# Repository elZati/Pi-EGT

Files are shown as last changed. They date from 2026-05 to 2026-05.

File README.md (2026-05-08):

# Pi-EGT

Marine boat instrument panel for Raspberry Pi 3 with a 5" DSI touchscreen (portrait mode, 480 × 800).

Displays exhaust gas temperature (EGT) in real time via a large circular analog gauge, logs a 15-minute rolling history, monitors ambient temperatures, and — when connected to WiFi — shows today's weather forecast and lightning storm risk.

---

## Hardware

| Component | Detail |
|---|---|
| Raspberry Pi 3 | Any variant |
| Raspberry Pi Touchscreen 2 (5") | DSI, 480 × 800 portrait |
| MAX31855 thermocouple amplifier | EGT sensor via SPI (CE0, 1 MHz) |
| DS18B20 temperature sensor(s) | Up to 2 on 1-Wire bus (GPIO 4) |
| Buzzer | EGT alarm via GPIO 17 (NPN transistor) |
| Custom HAT PCB | LM2596 buck converter from boat battery |

## Features

- **EGT gauge** — circular analog gauge with coloured zone arc (green / amber / red), digital readout and 15-minute scrolling histogram
- **Ambient temperature tiles** — shown automatically when DS18B20 sensors are detected; hidden if sensors disconnect (with 15-second timeout)
- **Buzzer alarm** — activates when EGT exceeds a configurable threshold
- **Weather panel** — today's forecast (icon, description, min/max °C) via [Open-Meteo](https://open-meteo.com/), selectable location
- **Lightning risk panel** — Low / Moderate / High / Active derived from CAPE and WMO weather codes
- **Adaptive poll rate** — 4 Hz normally, drops to 1 Hz if the Pi CPU exceeds 70 °C
- **Portrait layout** — all panels stack vertically; weather and lightning panels are hidden by default and revealed on demand (histogram hides to make room)
- **Setup dialog** — configure EGT gauge min/max, alarm threshold, and mock sensor mode without restarting
- **Fullscreen toggle** — hides the OS taskbar for a clean instrument view
- **Auto-start on boot** via XDG autostart (`~/.config/autostart/pi-egt.desktop`)

## Requirements

```
PyQt5 >= 5.15
requests >= 2.28
spidev >= 3.5      # Pi only
RPi.GPIO >= 0.7    # Pi only
```

Install on the Pi:

```bash
pip3 install -r requirements.txt
```

## Pi OS configuration

Add to `/boot/firmware/config.txt` and reboot:

```ini
dtparam=spi=on        # MAX31855
dtoverlay=w1-gpio     # DS18B20
```

## Running

```bash
cd ~/pi-egt
DISPLAY=:0 python3 main.py            # normal mode
DISPLAY=:0 python3 main.py --mock     # simulated sawtooth sensors
```

Mock mode can also be toggled at runtime from the **Setup** dialog.

## Deployment to Pi

```bash
# Copy project
scp -r . pi@<pi-ip>:~/pi-egt/

# Install desktop shortcut
ssh pi@<pi-ip> "cp ~/pi-egt/pi-egt.desktop ~/Desktop/ && chmod +x ~/Desktop/pi-egt.desktop"

# Install autostart (runs on every boot)
ssh pi@<pi-ip> "mkdir -p ~/.config/autostart && cp ~/pi-egt/pi-egt.desktop ~/.config/autostart/"
```

## Project structure

```
Pi-EGT/
├── main.py                   Entry point; --mock flag; dark Qt palette
├── pi-egt.desktop            Desktop / autostart launcher
├── requirements.txt
├── docs/
│   ├── notes.md              Hardware design notes, PCB, BOM
│   └── software.md           Full software description & architecture
└── pi_egt/
    ├── config.py             Constants and user config (load/save JSON)
    ├── sensors/
    │   ├── max31855.py       SPI thermocouple reader
    │   ├── ds18b20.py        1-Wire temperature reader
    │   └── buzzer.py         GPIO buzzer
    ├── network/
    │   ├── connectivity.py   TCP reachability check
    │   ├── weather.py        Open-Meteo API client
    │   ├── lightning.py      Lightning risk assessment
    │   └── fetch_thread.py   Non-blocking QThread fetch
    └── ui/
        ├── main_window.py    Main window, layout, timers
        └── widgets/
            ├── egt_gauge.py
            ├── histogram.py
            ├── temp_tile.py
            ├── weather_panel.py
            ├── lightning_panel.py
            ├── setup_dialog.py
            └── location_dialog.py
```

## License

MIT

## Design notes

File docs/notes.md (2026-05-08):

# Pi-EGT Boat Instrument — Hardware Notes

## Overview

Raspberry Pi 3 based boat instrument panel displaying EGT (exhaust gas temperature),
coolant temperature, and ambient temperatures. Includes alarm buzzer for EGT threshold.

---

## Power Supply

### LM2596 Buck Converter
- Input: 10–15V boat battery
- Output: 5V / 3A
- IC: LM2596S-5.0 (TO-263 SMD, fixed 5V)
- Switching frequency: 150kHz
- Input protection diode: SS34 on battery+ input (reverse polarity protection)

### LC Post Filter
- Inductor: 4.7µH (Wurth 7440530047)
- Capacitor: 100µF 10V tantalum D case
- Purpose: reduces LM2596 switching ripple before Pi supply

### Pi Power Connection
- Feed 5V to Pi GPIO header **pin 2** or **pin 4**
- GND to any Pi GND pin
- 100nF decoupling cap + 10µF bulk cap at Pi header pins
- Do NOT use micro USB for power in this installation

---

## GPIO Pin Assignments

| GPIO (BCM) | Physical pin | Function |
|---|---|---|
| GPIO4 | pin 7 | 1-Wire bus — DS18B20 temperature sensors |
| GPIO7 | pin 26 | SPI CE1 — MAX31855 #2 chip select |
| GPIO8 | pin 24 | SPI CE0 — MAX31855 #1 chip select |
| GPIO9 | pin 21 | SPI MISO — shared by both MAX31855 |
| GPIO11 | pin 23 | SPI SCLK — shared by both MAX31855 |
| GPIO17 | pin 11 | Buzzer driver output |

---

## Sensors

### DS18B20 — 1-Wire Temperature Sensors
- Two sensors on a single 1-Wire bus
- Protocol: Dallas 1-Wire
- Power: 3.3V from Pi header pin 1 (3-wire mode recommended for marine)
- Data pin: GPIO4 (Pi physical pin 7)
- Pull-up: single 4.7kΩ resistor from DQ to 3.3V (shared by all sensors)
- Connected via 3-position Phoenix Contact screw terminal (VDD / GND / DQ)

**Enable 1-Wire on Pi — add to `/boot/config.txt`:**
```
dtoverlay=w1-gpio
```

**Read temperature:**
```python
# Sensors appear as folders under /sys/bus/w1/devices/
# Named like: 28-xxxxxxxxxxxx
# Temperature in millidegrees C

import glob

sensor_paths = glob.glob('/sys/bus/w1/devices/28-*/temperature')

for path in sensor_paths:
    with open(path) as f:
        temp_mc = int(f.read())
        temp_c = temp_mc / 1000.0
        print(f'{path}: {temp_c:.1f}°C')
```

---

### MAX31855 — Thermocouple Amplifier (EGT + Coolant)
- Two MAX31855 boards (Adafruit breakout)
- Protocol: SPI (read-only, MISO only — no MOSI needed)
- Power: 3.3V
- MAX31855 #1 (EGT): CS on GPIO8 (CE0)
- MAX31855 #2 (Coolant/second EGT): CS on GPIO7 (CE1)
- SCLK: GPIO11 (shared)
- MISO: GPIO9 (shared)
- SPI clock speed: 1MHz recommended (tolerant of long cable run)

**Remote sensor connection:**
- Sensor located at aft of boat
- Connected to Pi hat via Molex 8-pin connector
- Series resistors on Pi hat side: 33Ω on CLK, CS1, CS2, MISO (GPIO protection)
- Common mode chokes on sensor side (already on Adafruit board)
- Cable: twist signal pairs with GND for noise rejection

**Molex 8-pin connector pinout:**

| Pin | Signal | Notes |
|-----|---|---|
| 8 | spare | — |
| 7 | 3.3V | Power |
| 6 | 3.3V | Second power pin |
| 5 | TH_3V0 | MAX31855 3V output — leave unconnected on Pi side |
| 4 | GND | Ground |
| 3 | TH_DO / MISO | Data from sensor |
| 2 | TH_CS / CE0 | Chip select — MAX31855 #1 |
| 1 | TH_CLK | SPI clock |

**Read thermocouple with Python:**
```python
import spidev

spi = spidev.SpiDev()
spi.open(0, 0)          # bus 0, CE0 — MAX31855 #1
spi.max_speed_hz = 1000000
spi.mode = 1

def read_max31855(cs):
    spi.open(0, cs)
    raw = spi.readbytes(4)
    spi.close()
    value = (raw[0] << 24) | (raw[1] << 16) | (raw[2] << 8) | raw[3]
    if value & 0x7:
        return None     # fault detected
    temp_raw = (value >> 18) & 0x3FFF
    if temp_raw & 0x2000:
        temp_raw -= 0x4000
    return temp_raw * 0.25

egt_temp   = read_max31855(0)   # CE0 — EGT sensor
cool_temp  = read_max31855(1)   # CE1 — coolant sensor
```

---

## Buzzer Alarm

- Buzzer: Same Sky CMI-1295-0585T (5V active, internally driven, through-hole, 5mm pin pitch)
- Driver: BC817-25 NPN transistor (SOT-23)
- GPIO: GPIO17 (Pi physical pin 11)
- Circuit: GPIO17 → 1kΩ R_BASE → transistor base, 10kΩ R_PULL to GND, SS14 flyback diode across buzzer
- Power: 5V rail

**Buzzer control:**
```python
import RPi.GPIO as GPIO

BUZZER_PIN = 17

GPIO.setmode(GPIO.BCM)
GPIO.setup(BUZZER_PIN, GPIO.OUT)

def buzzer_on():
    GPIO.output(BUZZER_PIN, GPIO.HIGH)

def buzzer_off():
    GPIO.output(BUZZER_PIN, GPIO.LOW)
```

**EGT alarm example:**
```python
EGT_ALARM_THRESHOLD = 800   # degrees C — adjust to suit engine

def check_egt_alarm(egt_temp):
    if egt_temp is not None and egt_temp > EGT_ALARM_THRESHOLD:
        buzzer_on()
    else:
        buzzer_off()
```

---

## Display

- 5 inch DSI touchscreen connected to Pi DSI port
- Draws 5V from Pi's 5V rail
- DSI interface logic handled internally by Pi
- No extra power wiring needed for display

---

## BOM Summary (DigiKey part numbers)

| Ref | Part number | Qty | Description |
|-----|---|-----|---|
| U1 | LM2596S-5.0/NOPB | 1 | DC-DC regulator IC |
| L1 | SRR1260-330M | 1 | 33µH main inductor |
| L2 | 7440530047 | 1 | 4.7µH post filter inductor |
| D1, D2 | SS34-HF | 2 | Schottky diode 3A/40V |
| D3 | SS14-E3/61T | 1 | Flyback diode buzzer |
| Q1 | BC817-25LT1G | 1 | NPN transistor buzzer driver |
| F1 | 3568-15 | 1 | ATO fuse holder 5A |
| BZ1 | CMI-1295-0585T | 1 | 5V active buzzer |
| C_OUT, C_POST | T491D107K010AT | 2 | 100µF 10V tantalum D case |
| C1-C3, C6 | CC0805KRX7R9BB104 | 4 | 100nF X7R 0805 |
| R4 | RC0805FR-074K7L | 1 | 4.7kΩ 1-Wire pull-up |
| R5,R6,R7,R10 | RC0805FR-0733RL | 4 | 33Ω SPI series resistors |
| R_BASE, R_ONOFF | RC0805FR-071KL | 2 | 1kΩ 0805 |
| R_PULL, R8 | RC0805FR-0710KL | 2 | 10kΩ 0805 |
| J_TEMP | 1751251 | 1 | Phoenix 3-pos 3.5mm terminal |
| J_PWR | 1715022 | 1 | Phoenix 2-pos 5mm terminal |

---

## PCB Design Rules (PCBWay standard 2-layer)

| Parameter | Value |
|---|---|
| Min clearance | 0.127mm |
| Min track width | 0.127mm |
| Min via diameter | 0.6mm |
| Min via drill | 0.3mm |
| Min hole to hole | 0.5mm |
| Hole clearance | 0.25mm |
| Copper to edge | 0.3mm |
| Min text height | 1.0mm |
| Min text stroke | 0.15mm |

### Recommended track widths

| Net | Width |
|-----|---|
| 5V power | 2.0mm |
| 3.3V power | 1.0mm |
| Signal (SPI, 1-Wire) | 0.25mm |
| LM2596 switch node | 2.5mm (short as possible) |

### Recommended via sizes

| Type | Outer dia | Drill |
|---|---|---|
| Signal | 0.8mm | 0.4mm |
| Power / GND stitch | 1.0mm | 0.5mm |
| LM2596 thermal (×6) | 1.0mm | 0.5mm |

---

## Useful Libraries for Pi Development

```bash
pip install RPi.GPIO spidev w1thermsensor adafruit-circuitpython-max31855
```

- `RPi.GPIO` — GPIO control (buzzer)
- `spidev` — raw SPI access (MAX31855)
- `w1thermsensor` — DS18B20 1-Wire (simpler than reading sysfs directly)
- `adafruit-circuitpython-max31855` — Adafruit MAX31855 library

---

## Notes

- Conformal coat all PCBs after assembly — marine salt air environment
- Enable Pi hardware watchdog in software for unattended operation
- Keep SPI clock at 1MHz for long cable run to aft sensor
- LM2596 switch node (pin 2 / inductor / catch diode) — keep traces short and wide
- Keep feedback trace (LM2596 pin 4) away from inductor
- LM2596 TO-263 tab needs copper pour + 6 thermal vias for heat dissipation
- Ground plane on B.Cu flood filled with GND net
- Stitch F.Cu and B.Cu ground planes with vias throughout board

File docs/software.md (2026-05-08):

# Pi-EGT Software — Description & Architecture

## What it is

Pi-EGT is a marine instrument panel application for Raspberry Pi 3 with a 5-inch DSI
touchscreen.  It displays exhaust gas temperature (EGT) and ambient temperatures in
real time, triggers a buzzer alarm when EGT exceeds a configurable threshold, and
optionally shows today's weather forecast and lightning storm risk when the Pi has a
network connection.

---

## Running the app

```bash
cd ~/pi-egt
DISPLAY=:0 python3 main.py          # real hardware
DISPLAY=:0 python3 main.py --mock   # simulated sensors (development)
```

`--mock` forces all sensors into simulation mode regardless of whether the hardware
interfaces are present.  Useful when the sensors are not yet connected.

Mock mode can also be toggled at runtime from the Setup dialog without restarting.

User settings (EGT range, alarm threshold, mock mode, saved location) are stored in
`~/.pi_egt/config.json` and loaded automatically on startup.

---

## Screen layout  (480 × 800 portrait, Raspberry Pi Touchscreen 2)

```
┌────────────── 480 ───────────────┐
│                                  │
│          EGT analog gauge        │  stretch 8
│       (large circular, full      │
│        width, dominant)          │
│                                  │
├──────────────────────────────────┤
│       15-minute EGT histogram    │  stretch 2
├──────────────────────────────────┤
│   Ambient 1    │    Ambient 2    │  stretch 2 (hidden if no sensors)
├──────────────────────────────────┤
│       Lightning risk panel       │  stretch 2 (hidden by default)
├──────────────────────────────────┤
│       Weather panel              │  stretch 2 (hidden by default)
├──────────────────────────────────┤
│ [⚙ Setup][⚡ Ltng][▼ Wth][⛶ Full]│  fixed 44 px
└──────────────────────────────────┘
```

All sections stack top-to-bottom (portrait orientation).

**Dynamic visibility rules:**
- Ambient temperature row appears only when DS18B20 sensors are detected (or mock
  mode is active).  Hidden entirely when no 1-Wire sensors are found.
- Lightning panel is hidden on startup.  Tap **⚡ Lightning** to reveal it.
- Weather panel is hidden on startup.  Tap **▼ Weather** to reveal it.

---

## Sensors

### MAX31855 — EGT thermocouple (SPI)

| Item | Detail |
|---|---|
| Interface | SPI bus 0, CE0 (`/dev/spidev0.0`) |
| Clock speed | 1 MHz (tolerant of long cable run to aft sensor) |
| Poll rate | 1 second |
| Mock | Sawtooth 0 → 1000 °C, period ~120 s |

`None` is returned on any fault condition (open circuit, short to VCC/GND).  The
gauge shows **FAULT** and the buzzer stays silent.

### DS18B20 — Ambient temperature (1-Wire)

| Item | Detail |
|---|---|
| Interface | 1-Wire on GPIO 4 (`/sys/bus/w1/devices/28-*`) |
| Sensors | Up to 2 on one bus |
| Poll rate | 1 second (same timer as EGT) |
| Mock | Sawtooth 0 → 100 °C, period ~60 s; sensor 2 offset by 50 °C |

If the 1-Wire bus is present but no `28-*` sensor files are found, the driver
automatically falls back to mock data rather than showing blank tiles.

The `sensor_count` property exposes how many sensors are active (2 in mock mode,
actual discovered count in hardware mode).  `MainWindow` uses this to show or hide
the ambient temperature tiles dynamically.

### Buzzer — EGT alarm (GPIO 17)

Driven via NPN transistor (BC817-25).  The buzzer activates whenever the EGT reading
exceeds the configured alarm threshold.  It deactivates as soon as the reading drops
back below the threshold.  On Pi OS the driver uses `RPi.GPIO`; off-Pi it is a no-op.

---

## EGT gauge

A custom `QPainter`-drawn circular gauge rendered in a virtual 300 × 300 coordinate
space and scaled to fill the available widget area.

**Configurable range** — the gauge min, max, and alarm threshold are all user-settable
via the Setup dialog.  Changes take effect immediately without restarting.

**Zone colours** — derived at runtime from the alarm threshold:

| Zone | Range | Colour |
|---|---|---|
| Safe | min → alarm × 0.85 | Green `#27ae60` |
| Caution | alarm × 0.85 → alarm | Amber `#f39c12` |
| Danger | alarm → max | Red `#e74c3c` |

When the alarm threshold changes the colour arc boundaries redraw automatically.

**Tick labels** — font 11 px bold, placed at radius 76 (well inside the colour arc at
radius 110) so they never overlap the arc.  Step size is computed from the display
range (100 °C steps for 0–1000 °C, 50 °C for smaller ranges, etc.).

---

## 15-minute EGT histogram

Keeps a rolling `deque` of `(monotonic_timestamp, temperature)` pairs covering the
last 15 minutes (900 seconds).  Readings older than 15 minutes are pruned on every
new reading.

The histogram spans the full window width below the top row.

The Y-axis scale matches the gauge max setting and redraws correctly when the range
is changed via Setup.  Grid-line and label steps are computed dynamically:

| Max temp | Step |
|---|---|
| ≤ 200 °C | 50 °C |
| ≤ 500 °C | 100 °C |
| > 500 °C | 200 °C |

---

## Setup dialog

Opened via the **⚙ Setup** button (bottom-left, 44 px tall touch target).

| Setting | Default | Step | Range |
|---|---|---|---|
| Gauge Min | 0 °C | 50 °C | 0 – 500 °C |
| Gauge Max | 1000 °C | 50 °C | 200 – 1200 °C |
| Alarm Threshold | 800 °C | 10 °C | 100 – 1200 °C |
| Mock Sensors | OFF | toggle | — |

On **Save**:
- Alarm is automatically clamped to the display range.
- Gauge Min is clamped so that Max − Min ≥ 100 °C.
- Values are applied immediately to the gauge, histogram, and alarm logic.
- If mock mode changed, sensors are re-initialised in place and tile visibility
  is updated without restarting the app.
- Settings are persisted to `~/.pi_egt/config.json`.

---

## Weather panel

Requires an internet connection (checked before every fetch via a TCP probe to
`8.8.8.8:53`).  When offline, all panels show "No network" and retry on the next
scheduled tick.

**Hidden by default** — tap **▼ Show weather** to reveal it.  The button turns green
when weather is hidden as a reminder that it is available.

**Data source:** [Open-Meteo](https://open-meteo.com/) — free, no API key required.

**What is shown:**
- Location name (city)
- Today's dominant weather icon and description (WMO weather code)
- Today's min / max temperature (°C)

**Location selection:** tap the **⚙** button inside the weather panel to open a city
search dialog.  The geocoding API is also Open-Meteo.  Selected location is saved to
`~/.pi_egt/config.json`.

**Sensor poll rate:** adaptive — 250 ms (4 Hz) normally; drops to 1000 ms when the
Pi CPU temperature exceeds 70 °C, and restores once it falls back below 65 °C.
The CPU temperature is sampled every 10 seconds from
`/sys/class/thermal/thermal_zone0/temp`.  On non-Pi hardware the fast rate is
always used.

**Fetch interval:** every 15 minutes.  Each fetch runs in a one-shot `QThread`
(`FetchThread`) so the UI is never blocked.  After the thread finishes it is deleted
and the reference cleared; only one fetch runs at a time.

**Connectivity retry:** the first fetch fires 10 seconds after startup (to give WiFi
time to connect on autostart).  If the network is unreachable, the app retries every
30 seconds for up to 10 minutes (20 attempts).  The retry stops automatically on the
first successful fetch; the regular 15-minute timer continues independently.

---

## Lightning risk panel

Derived from the same Open-Meteo fetch as the weather data (no separate API call).
Full width, hidden by default — tap **⚡ Lightning** to show it.

| Level | Trigger |
|---|---|
| Low | Default — no elevated CAPE or thunderstorm code |
| Moderate | CAPE ≥ 500 J/kg  or  lightning potential ≥ 40 % |
| High | CAPE ≥ 1000 J/kg  or  lightning potential ≥ 70 % |
| Active | Current-hour WMO weather code is 95, 96, or 99 (thunderstorm) |

When **Active**, the panel background turns dark red as a visual alarm.

---

## Panel toggles

Four buttons in the 44 px bar at the bottom control what is visible:

| Button | Hidden state | Shown state |
|---|---|---|
| ⚡ Lightning | Yellow tint | Normal, "Hide lightning" |
| ▼ Weather | Green tint | Normal, "▲ Hide weather" |

When a panel is hidden its stretch is removed from the layout, giving more vertical
space to the gauge and histogram.  Both panels are hidden on startup.

---

## Fullscreen toggle

The **⛶ Fullscreen** button (44 px, bottom-right) switches between windowed and
fullscreen mode.  In fullscreen mode the OS taskbar and window decorations are
hidden, giving the instrument the full 800 × 480 display.  Pressing **⊞ Windowed**
restores the normal windowed view.

---

## Desktop shortcut

`pi-egt.desktop` in the project root is a standard `.desktop` launcher for the Pi OS
desktop environment.  To install it on the Pi:

```bash
cp ~/pi-egt/pi-egt.desktop ~/Desktop/
chmod +x ~/Desktop/pi-egt.desktop
```

The shortcut launches the app from the desktop without opening a terminal.

---

## Auto-start on boot

`~/.config/autostart/pi-egt.desktop` is installed on the Pi.  The XDG autostart
mechanism starts the app automatically whenever the desktop session loads (Pi OS
auto-logs in as `pi` by default, so this fires on every boot).

A `sleep 8` delay is built into the launch command to give the display server time
to finish initialising before the app starts.

To disable auto-start:
```bash
rm ~/.config/autostart/pi-egt.desktop
```

---

## Project structure

```
Pi-EGT/
├── main.py                        Entry point; --mock flag; dark Qt palette
├── pi-egt.desktop                 Desktop shortcut (copy to ~/Desktop/ on Pi)
├── requirements.txt
├── docs/
│   ├── notes.md                   Hardware design notes, PCB, BOM
│   └── software.md                This file
└── pi_egt/
    ├── config.py                  All constants + user config load/save
    ├── sensors/
    │   ├── max31855.py            SPI reader / sawtooth mock
    │   ├── ds18b20.py             1-Wire reader / sawtooth mock; sensor_count property
    │   └── buzzer.py              GPIO buzzer / no-op mock
    ├── network/
    │   ├── connectivity.py        TCP reachability check
    │   ├── weather.py             Open-Meteo API client (weather + geocoding)
    │   ├── lightning.py           Lightning risk assessment from weather data
    │   └── fetch_thread.py        One-shot QThread for non-blocking fetch
    └── ui/
        ├── main_window.py         QMainWindow — vertical layout, timers, signal wiring
        └── widgets/
            ├── egt_gauge.py       Circular analog gauge (QPainter)
            ├── histogram.py       15-minute scrolling EGT chart (QPainter)
            ├── temp_tile.py       Digital ambient temperature tile
            ├── weather_panel.py   Compact today-only weather display
            ├── lightning_panel.py Lightning risk level display
            ├── setup_dialog.py    EGT range + alarm + mock mode configuration
            └── location_dialog.py City search + selection dialog
```

---

## Pi configuration requirements

The following must be enabled in `/boot/firmware/config.txt` before the hardware
sensors will work:

```ini
dtparam=spi=on        # MAX31855 thermocouple
dtoverlay=w1-gpio     # DS18B20 1-Wire sensors
```

A reboot is required after enabling these overlays.

---

## Dependencies

| Package | Purpose | Pi only? |
|---|---|---|
| `PyQt5 ≥ 5.15` | UI framework | No |
| `requests ≥ 2.28` | Weather API HTTP | No |
| `spidev ≥ 3.5` | MAX31855 SPI | Yes |
| `RPi.GPIO ≥ 0.7` | Buzzer GPIO | Yes |

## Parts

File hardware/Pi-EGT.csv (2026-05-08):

Reference | Value | Datasheet | Footprint | Qty | DNP
BZ1 | Buzzer |  | Buzzer_Beeper:Buzzer_TDK_PS1240P02BT_D12.2mm_H6.5mm | 1
C1,C2,C3,C6 | 100n | https://cdn.sparkfun.com/assets/8/a/4/a/5/Kemet_Capacitor_Datasheet.pdf | Capacitor_SMD:C_0805_2012Metric_Pad1.18x1.45mm_HandSolder | 4
C4,C7 | 100u |  | Capacitor_Tantalum_SMD:CP_EIA-7343-20_Kemet-V_HandSolder | 2
C5 | 220u |  | Capacitor_Tantalum_SMD:CP_EIA-7343-20_Kemet-V_HandSolder | 1
D1,D2 | SS34 | https://www.vishay.com/docs/88751/ss32.pdf | Diode_SMD:D_SMA | 2
D4 | SS14 | https://www.vishay.com/docs/89018/mss1p6.pdf | PCM_SparkFun-Semiconductor-Standard:SMA | 1
F1 | Fuse |  | Fuse:Fuseholder_Blade_Mini_Keystone_3568 | 1
J1 | GPIO |  | Connector_PinSocket_2.54mm:PinSocket_2x20_P2.54mm_Vertical | 1
J2,J6 | 446200001 |  | EGT-Connector:CON_SD44620_15P75X15P11_MOL | 2
J4 | 3.5mm | https://cdn.sparkfun.com/assets/b/1/8/d/9/OSTTEXX0104.pdf | TerminalBlock_Phoenix:TerminalBlock_Phoenix_PT-1,5-3-3.5-H_1x03_P3.50mm_Horizontal | 1
J5 | Screw_Terminal_01x02 |  | TerminalBlock_Phoenix:TerminalBlock_Phoenix_MKDS-3-2-5.08_1x02_P5.08mm_Horizontal | 1
L1 | L_Ferrite_Small |  | Inductor_SMD:L_Bourns_SRR1260 | 1
L2 | 4.7 uH | https://www.we-online.com/catalog/datasheet/7440530047.pdf?ki | Wurth_coils:L_Wurth_WE-TPC-5828 | 1
Q1 | BC817 | https://www.onsemi.com/pub/Collateral/BC818-D.pdf | Package_TO_SOT_SMD:SOT-23 | 1
R4 | 4k7 |  | Resistor_SMD:R_0805_2012Metric_Pad1.20x1.40mm_HandSolder | 1
R5,R6,R7,R10 | 33 |  | Resistor_SMD:R_0805_2012Metric_Pad1.20x1.40mm_HandSolder | 4
R8 | 10k |  | Resistor_SMD:R_0805_2012Metric_Pad1.20x1.40mm_HandSolder | 1
R9 | 1k |  | Resistor_SMD:R_0805_2012Metric_Pad1.20x1.40mm_HandSolder | 1
U2 | LM2596S-5 | http://www.ti.com/lit/ds/symlink/lm2596.pdf | Package_TO_SOT_SMD:TO-263-5_TabPin3 | 1

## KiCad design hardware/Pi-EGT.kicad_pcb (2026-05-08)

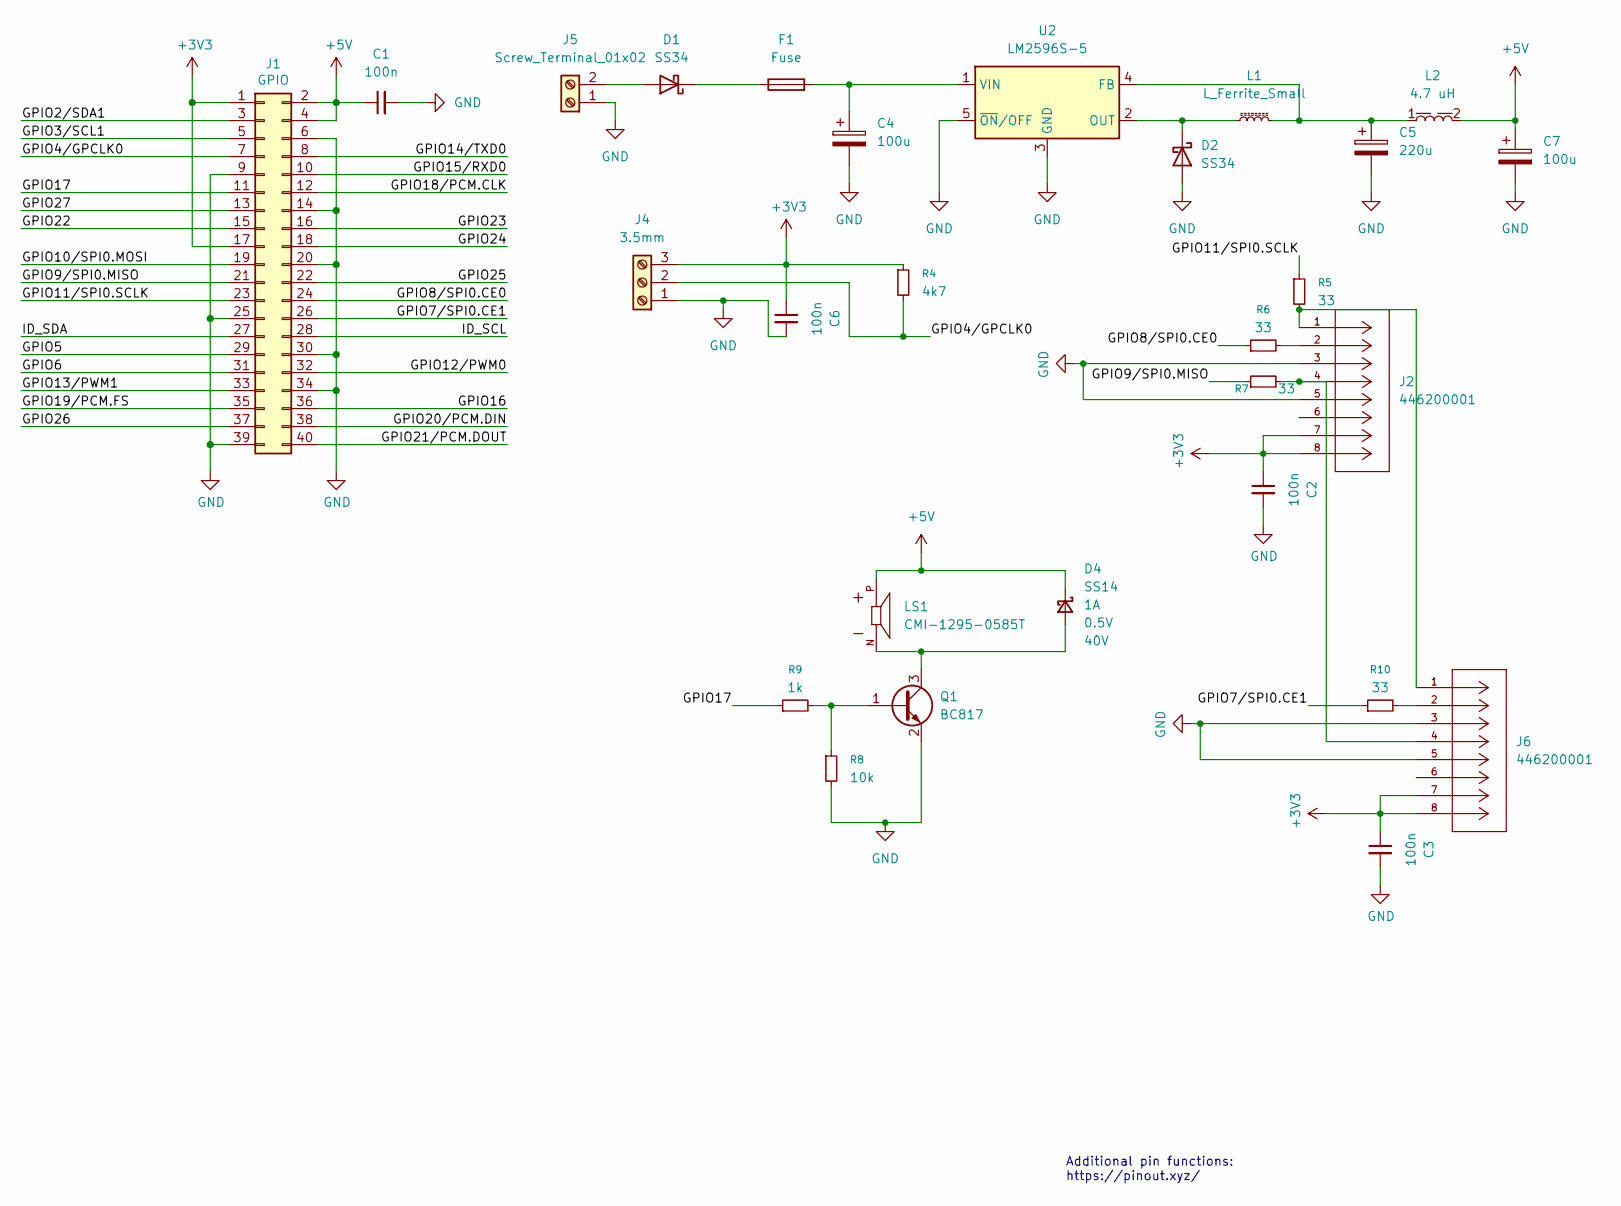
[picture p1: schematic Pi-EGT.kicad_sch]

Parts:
C1, C2, C3, C6: 100n; C_0805_2012Metric_Pad1.18x1.45mm_HandSolder; Voltage 1kV; Tolerance 100%
C4, C7: 100u; CP_EIA-7343-20_Kemet-V_HandSolder
C5: 220u; CP_EIA-7343-20_Kemet-V_HandSolder
D1, D2: SS34; D_SMA
D4: SS14; SMA
F1: Fuse; Fuseholder_Blade_Mini_Keystone_3568
J1: GPIO; PinSocket_2x20_P2.54mm_Vertical
J2, J6: 446200001; CON_SD44620_15P75X15P11_MOL; MANUFACTURER_PART_NUMBER 446200001
J4: 3.5mm; TerminalBlock_Phoenix_PT-1,5-3-3.5-H_1x03_P3.50mm_Horizontal
J5: Screw_Terminal_01x02; TerminalBlock_Phoenix_MKDS-3-2-5.08_1x02_P5.08mm_Horizontal
L1: L_Ferrite_Small; L_Bourns_SRR1260
L2: 4.7 uH; L_Wurth_WE-TPC-5828; Part Number 7440530047
LS1: CMI-1295-0585T; CUI_CMI-1295-0585T; PARTREV N/A
Q1: BC817; SOT-23
R4: 4k7; R_0805_2012Metric_Pad1.20x1.40mm_HandSolder
R5, R6, R7, R10: 33; R_0805_2012Metric_Pad1.20x1.40mm_HandSolder
R8: 10k; R_0805_2012Metric_Pad1.20x1.40mm_HandSolder
R9: 1k; R_0805_2012Metric_Pad1.20x1.40mm_HandSolder
U2: LM2596S-5; TO-263-5_TabPin3

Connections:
+3V3: C2.1, C3.1, C6.1, J1.1, J1.17, J2.7, J2.8, J4.3, J6.7, J6.8, R4.1
+5V: C1.1, C7.1, D4.1 (K), J1.2, J1.4, L2.2, LS1.P
/GPIO2/SDA1: J1.3
/GPIO3/SCL1: J1.5
/GPIO4/GPCLK0: J1.7, J4.2, R4.2
/GPIO5: J1.29
/GPIO6: J1.31
/GPIO7/SPI0.CE1: J1.26, R10.1
/GPIO8/SPI0.CE0: J1.24, R6.1
/GPIO9/SPI0.MISO: J1.21, R7.1
/GPIO10/SPI0.MOSI: J1.19
/GPIO11/SPI0.SCLK: J1.23, R5.1
/GPIO12/PWM0: J1.32
/GPIO13/PWM1: J1.33
/GPIO14/TXD0: J1.8
/GPIO15/RXD0: J1.10
/GPIO16: J1.36
/GPIO17: J1.11, R9.1
/GPIO18/PCM.CLK: J1.12
/GPIO19/PCM.FS: J1.35
/GPIO20/PCM.DIN: J1.38
/GPIO21/PCM.DOUT: J1.40
/GPIO22: J1.15
/GPIO23: J1.16
/GPIO24: J1.18
/GPIO25: J1.22
/GPIO26: J1.37
/GPIO27: J1.13
/ID_SCL: J1.28
/ID_SDA: J1.27
GND: C1.2, C2.2, C3.2, C4.2, C5.2, C6.2, C7.2, D2.2 (A), J1.6, J1.9, J1.14, J1.20, J1.25, J1.30, J1.34, J1.39, J2.3, J2.5, J4.1, J5.1, J6.3, J6.5, Q1.2 (E), R8.2, U2.3 (GND), U2.5 (~ON/OFF)
unnamed: D1.2 (A), J5.2
unnamed: D1.1 (K), F1.1
unnamed: D2.1 (K), L1.1, U2.2 (OUT)
unnamed: D4.2 (A), LS1.N, Q1.3 (C)
unnamed: J2.1, J6.1, R5.2
unnamed: J2.2, R6.2
unnamed: J2.4, J6.4, R7.2
unnamed: J6.2, R10.2
unnamed: Q1.1 (B), R8.1, R9.2
unnamed: C5.1, L1.2, L2.1, U2.4 (FB)
unnamed: C4.1, F1.2, U2.1 (VIN)

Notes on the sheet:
Additional pin functions: https://pinout.xyz/

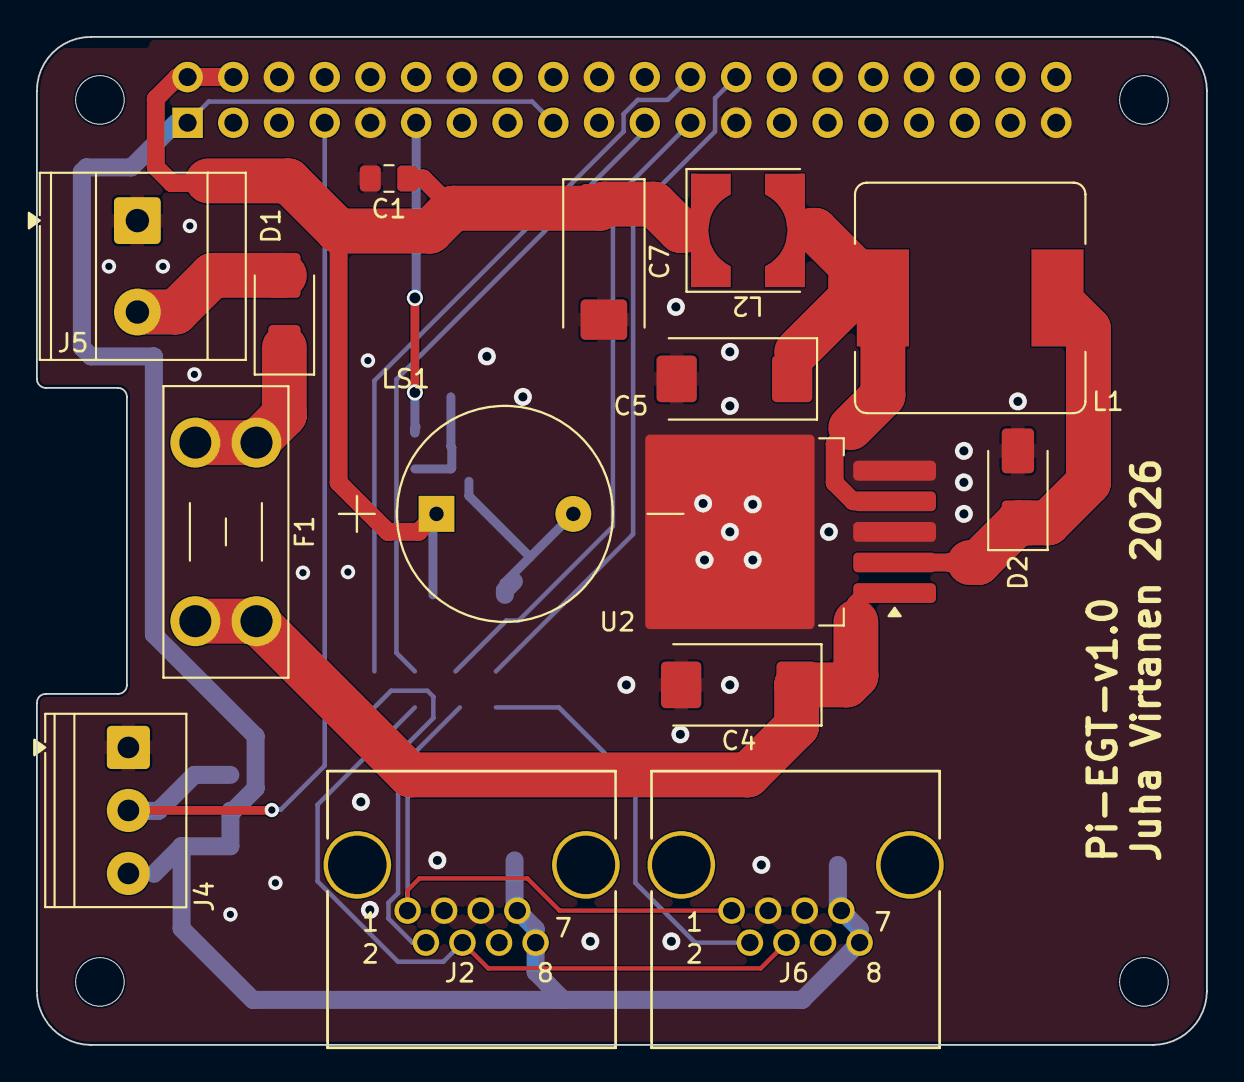
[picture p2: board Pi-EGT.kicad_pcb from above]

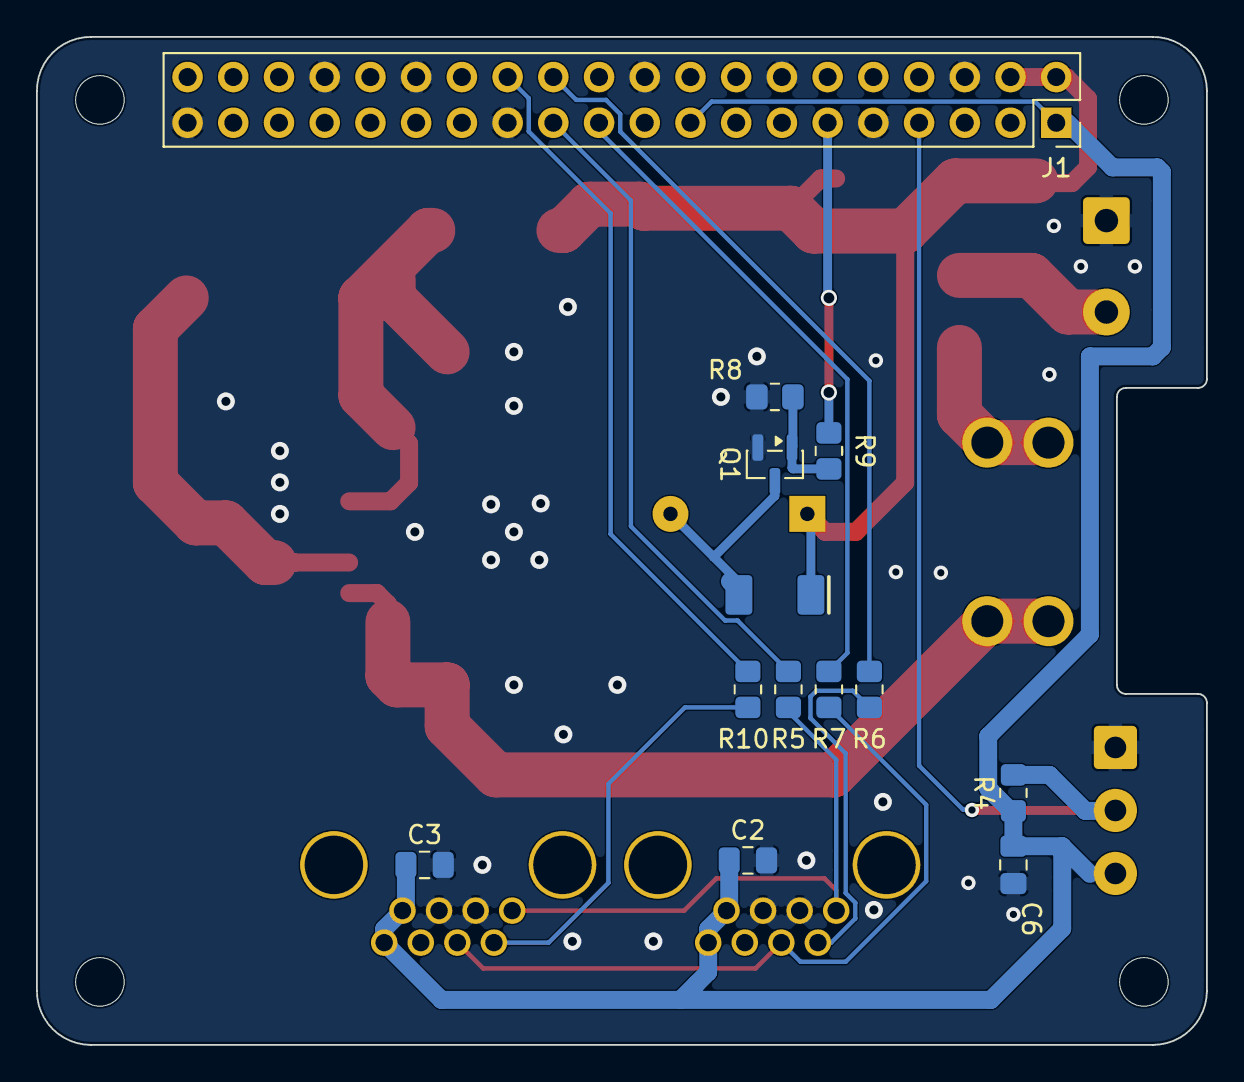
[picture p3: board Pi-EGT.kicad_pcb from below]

Board: 2 copper layers, 65.0 x 56.0 mm, 32 parts (13 on the bottom side), 20 nets.

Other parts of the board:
MH1, MH2, MH3, MH4: MountingHole_2.7mm_M2.5

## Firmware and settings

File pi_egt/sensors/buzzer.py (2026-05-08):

from __future__ import annotations

import os
import sys

_HAS_GPIO = sys.platform == 'linux' and os.path.exists('/dev/gpiomem')

if _HAS_GPIO:
    import RPi.GPIO as GPIO  # type: ignore


class Buzzer:
    """
    Active-buzzer driver via NPN transistor on a BCM GPIO pin.
    No-ops silently when running off-Pi.
    """

    def __init__(self, pin: int) -> None:
        self._pin = pin
        self._mock = not _HAS_GPIO
        self._active = False
        if not self._mock:
            GPIO.setmode(GPIO.BCM)
            GPIO.setup(pin, GPIO.OUT, initial=GPIO.LOW)

    @property
    def active(self) -> bool:
        return self._active

    def on(self) -> None:
        if self._active:
            return
        self._active = True
        if not self._mock:
            GPIO.output(self._pin, GPIO.HIGH)

    def off(self) -> None:
        if not self._active:
            return
        self._active = False
        if not self._mock:
            GPIO.output(self._pin, GPIO.LOW)

    def cleanup(self) -> None:
        self.off()
        if not self._mock:
            GPIO.cleanup(self._pin)

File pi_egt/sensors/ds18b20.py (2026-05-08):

from __future__ import annotations

import glob
import os

from pi_egt import config

_HAS_1WIRE = os.path.exists('/sys/bus/w1/devices')


class DS18B20:
    """
    Reader for DS18B20 sensors on the 1-Wire bus (GPIO4 / sysfs).
    Falls back to gentle sine-wave mocks when running off-Pi.
    """

    # Sawtooth: 0→100 °C over 60 s (~1.67 °C/s at 1 Hz poll), offset per sensor
    _MOCK_MAX = 100.0
    _MOCK_STEP = _MOCK_MAX / 60.0
    _MOCK_OFFSETS = [0.0, _MOCK_MAX / 2]   # sensor 2 starts mid-ramp

    def __init__(self) -> None:
        self._mock = config.MOCK_SENSORS or not _HAS_1WIRE
        self._paths: list[str] = []
        self._mock_vals = list(self._MOCK_OFFSETS)
        if not self._mock:
            self._discover()

    # ── Public API ───────────────────────────────────────────────────────────

    @property
    def sensor_count(self) -> int:
        """Number of sensors currently providing data (2 in mock, discovered count in hardware)."""
        if self._mock:
            return 2
        return len(self._paths)

    def read_all_celsius(self) -> list[float | None]:
        """Return temperature list, one entry per discovered sensor (None = read error)."""
        if self._mock:
            return self._mock_readings()
        if not self._paths:
            self._discover()  # retry on every poll until sensors appear (supports hot-plug)
        return self._hw_readings()

    # ── Hardware path ─────────────────────────────────────────────────────────

    def _discover(self) -> None:
        self._paths = sorted(glob.glob('/sys/bus/w1/devices/28-*/temperature'))

    def _hw_readings(self) -> list[float | None]:
        results: list[float | None] = []
        for path in self._paths:
            try:
                with open(path) as f:
                    results.append(int(f.read().strip()) / 1000.0)
            except OSError:
                results.append(None)
        return results

    # ── Mock path ─────────────────────────────────────────────────────────────

    def _mock_readings(self) -> list[float | None]:
        readings: list[float | None] = []
        for i in range(len(self._mock_vals)):
            readings.append(self._mock_vals[i])
            self._mock_vals[i] = (self._mock_vals[i] + self._MOCK_STEP) % self._MOCK_MAX
        return readings

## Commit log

2026-05-08 Initial commit: Pi-EGT boat instrument panel
    PyQt5 application for Raspberry Pi 3 with 5" DSI touchscreen.
    Displays EGT (MAX31855 SPI), ambient temperatures (DS18B20 1-Wire),
    15-minute EGT histogram, weather forecast and lightning risk via
    Open-Meteo. Portrait layout (480×800), adaptive sensor poll rate,
    auto-start on boot.
2026-05-08 Add KiCad hardware design files
    Schematic, PCB layout, BOM (CSV) and Gerber fabrication files
    for the custom Raspberry Pi HAT. Gerber-v1.zip is the production
    package sent for PCB manufacturing.
    [Pi-EGT-B_Courtyard.gbr, Pi-EGT-B_Cu.gbl, Pi-EGT-B_Mask.gbs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]
2026-05-08 Add three-layer watchdog: run.sh crash wrapper, hardware /dev/watchdog, software poll-stall restart
    - run.sh: shell loop restarts app 3 s after any exit/crash
    - /dev/watchdog: fed every 10 s from CPU timer; Pi reboots after ~60 s if app hangs
    - Software watchdog: 15 s QTimer; os.execv restart if sensor poll stalls >60 s
    - WATCHDOG_POLL_TIMEOUT_S = 60.0 added to config.py
    - closeEvent and _restart() both disarm /dev/watchdog with magic 'V' byte
